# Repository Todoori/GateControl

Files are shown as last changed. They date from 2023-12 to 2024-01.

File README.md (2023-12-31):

# PCBProjectTemplate
Use this Repository as a Template to start your PCB Project. It contatins the general structure that should be used.
You can also add Images and [links](https://www.youtube.com/watch?v=dQw4w9WgXcQ) if needed. 

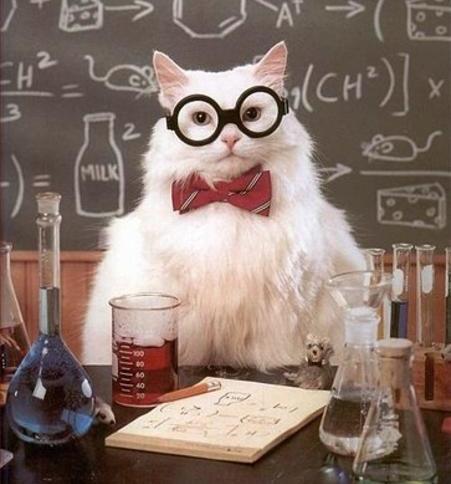
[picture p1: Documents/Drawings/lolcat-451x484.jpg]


## Assembly Instructions
- Do not solder those parts
- solder this solder bridge
- Do not soldet that solder bridge
- Use this part for R_example
- Be extra careful soldering this and that
- Do not aply to much heat to this part
- 
- 
- 

## Usage Instructions
- Try not to tuch this when PCB is on
- Use this software for programing that IC
- Here are some measurement Points
- 
- 
- 

## Additional Information

Feel free to add Information that you thing might be useful.

e.g. how a IC is connected on your Board:
### Pinout on Board

| PICO GPIO PIN  | Connected to |
| ---  | --- |
| 0  | |*|
| 1  | INT (CAN)|
| 2  | SPI0 SCK (CAN)|
| 3  | SPI0 TX (MOSI on Pico) (CAN)|
| 4  | SPI0 RX (MISO on Pico) (CAN)|
| 5  | SPIO0 CS (CAN)|
| 6  | LED Fault|
| 7  | |*|
| 8  | D7|
| 9  | D8|
| 10  | D9|
| 11  | D10|
| 12  | SPI1 RX (ADC)|
| 13  | SPI1 CS (ADC)|
| 14  | SPI1 SCK (ADC)|
| 15  | SPI1 TX (ADC)|
| 16  | D5|
| 17  | D6|
| 18  | D3|
| 19  | D4|
| 20  | D1|
| 21  | D2|
| 22  | |*|
| 23  | |*|
| 24  | |*|
| 25  | |*|
| 26  | A1|
| 27  | A2|
| 28  | SHUNT_ADC|

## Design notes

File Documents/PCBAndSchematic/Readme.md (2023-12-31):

# For easier it is a good Idea to export your schematic and pcb as PDF or Image, store them in here and display them in your main/readme. If you do not change their name but only update the file, you do not have to change the readme

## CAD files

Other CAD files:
DesignFiles/CAD/untitled.blend

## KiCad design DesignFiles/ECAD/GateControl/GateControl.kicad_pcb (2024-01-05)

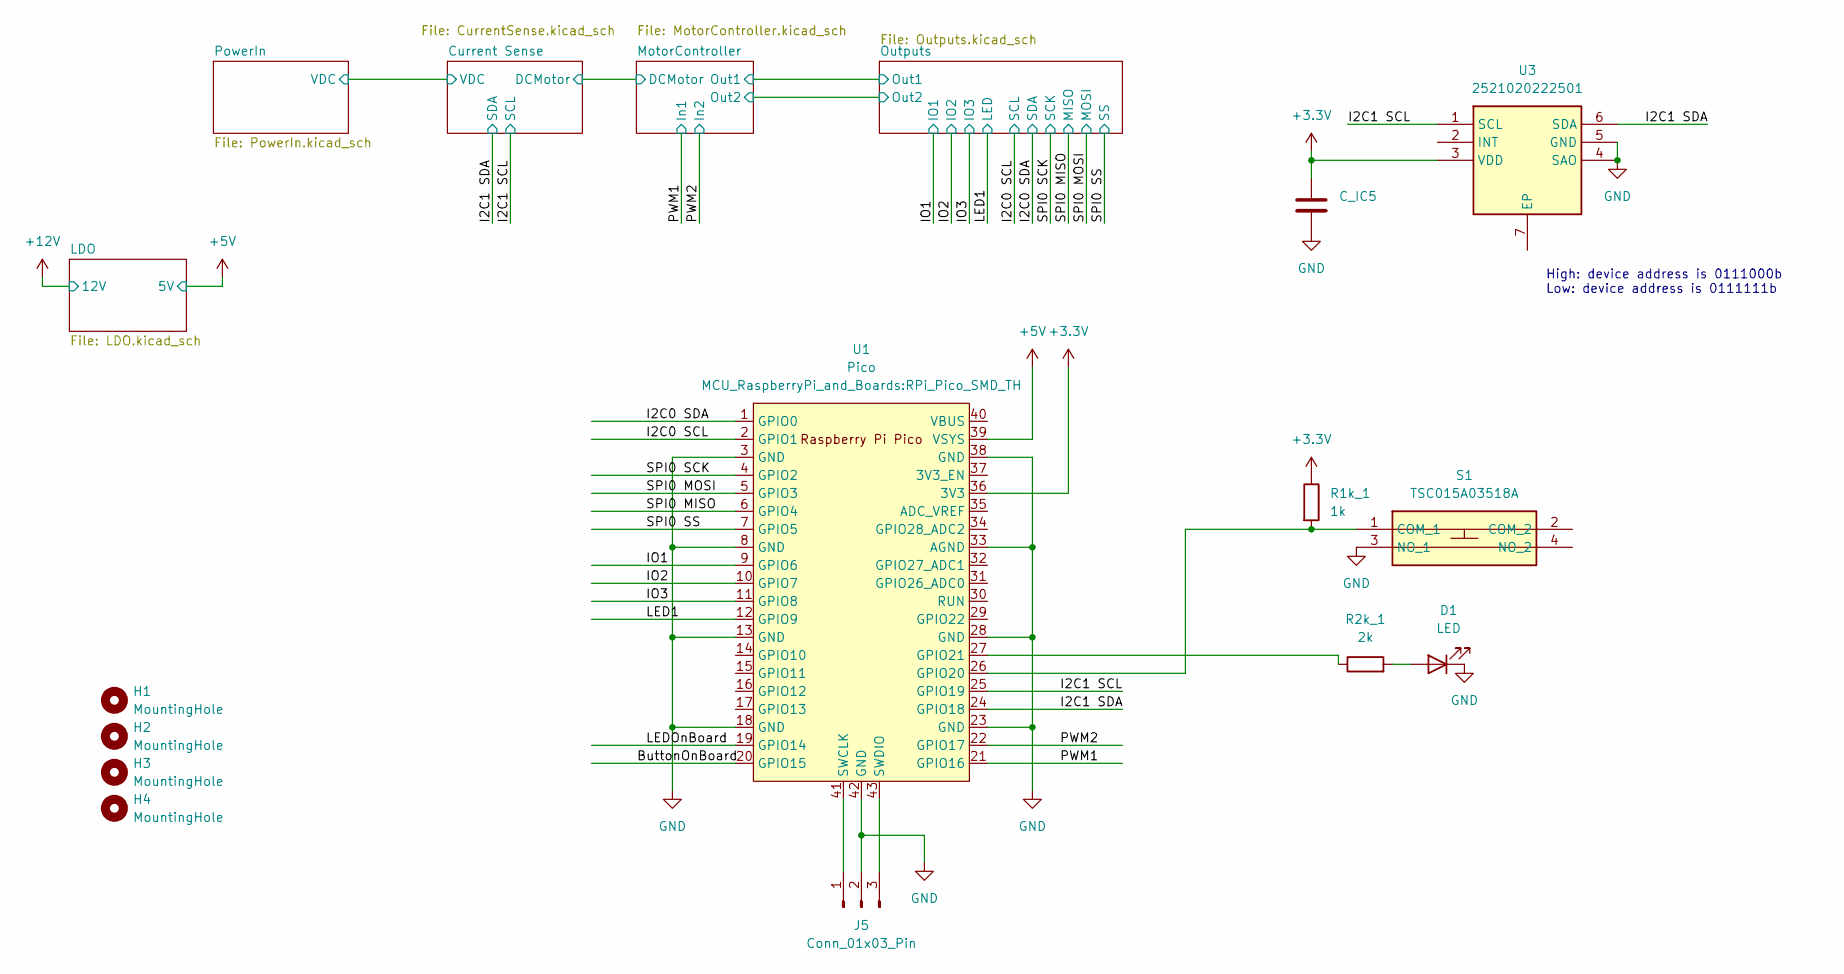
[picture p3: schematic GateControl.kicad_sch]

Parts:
C_IC5: C_Disc_D5.0mm_W2.5mm_P5.00mm
D1: LED; LED_0603_1608Metric_Pad1.05x0.95mm_HandSolder
H1, H2, H3, H4: MountingHole; MountingHole_3.2mm_M3_DIN965
J5: Conn_01x03_Pin; PinSocket_1x03_P2.54mm_Vertical
R1k_1: 1k; R_Axial_DIN0207_L6.3mm_D2.5mm_P7.62mm_Horizontal
R2k_1: 2k; R_0805_2012Metric_Pad1.20x1.40mm_HandSolder
S1: TSC015A03518A; Manufacturer_Part_Number TSC015A03518A
U1: Pico; RPi_Pico_SMD_TH
U3: 2521020222501; SON65P200X200X55-7N-D; Manufacturer_Part_Number 2521020222501; Mouser Part Number 710-2521020222501

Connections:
+3.3V: C_IC5.1, R1k_1.1, U1.36 (3V3), U3.3 (VDD); also elsewhere on the board
+5V: U1.39 (VSYS); also elsewhere on the board
/ButtonOnBoard: U1.20 (GPIO15)
/I2C0 SCL: U1.2 (GPIO1); also elsewhere on the board
/I2C0 SDA: U1.1 (GPIO0); also elsewhere on the board
/I2C1 SCL: U1.25 (GPIO19), U3.1 (SCL); also elsewhere on the board
/I2C1 SDA: U1.24 (GPIO18), U3.6 (SDA); also elsewhere on the board
/IO1: U1.9 (GPIO6); also elsewhere on the board
/IO2: U1.10 (GPIO7); also elsewhere on the board
/IO3: U1.11 (GPIO8); also elsewhere on the board
/LED1: U1.12 (GPIO9); also elsewhere on the board
/LEDOnBoard: U1.19 (GPIO14)
/PWM1: U1.21 (GPIO16); also elsewhere on the board
/PWM2: U1.22 (GPIO17); also elsewhere on the board
/SPI0 MISO: U1.6 (GPIO4); also elsewhere on the board
/SPI0 MOSI: U1.5 (GPIO3); also elsewhere on the board
/SPI0 SCK: U1.4 (GPIO2); also elsewhere on the board
/SPI0 SS: U1.7 (GPIO5); also elsewhere on the board
GND: C_IC5.2, D1.1 (K), J5.2, S1.3 (NO_1), U1.3 (GND), U1.8 (GND), U1.13 (GND), U1.18 (GND), U1.23 (GND), U1.28 (GND), U1.33 (AGND), U1.38 (GND), U1.42 (GND), U3.4 (SAO), U3.5 (GND); also elsewhere on the board
unnamed: D1.2 (A), R2k_1.2
unnamed: J5.1, U1.41 (SWCLK)
unnamed: J5.3, U1.43 (SWDIO)
unnamed: R1k_1.2, S1.1 (COM_1), U1.26 (GPIO20)
unnamed: R2k_1.1, U1.27 (GPIO21)

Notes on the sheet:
High: device address is 0111000b Low: device address is 0111111b

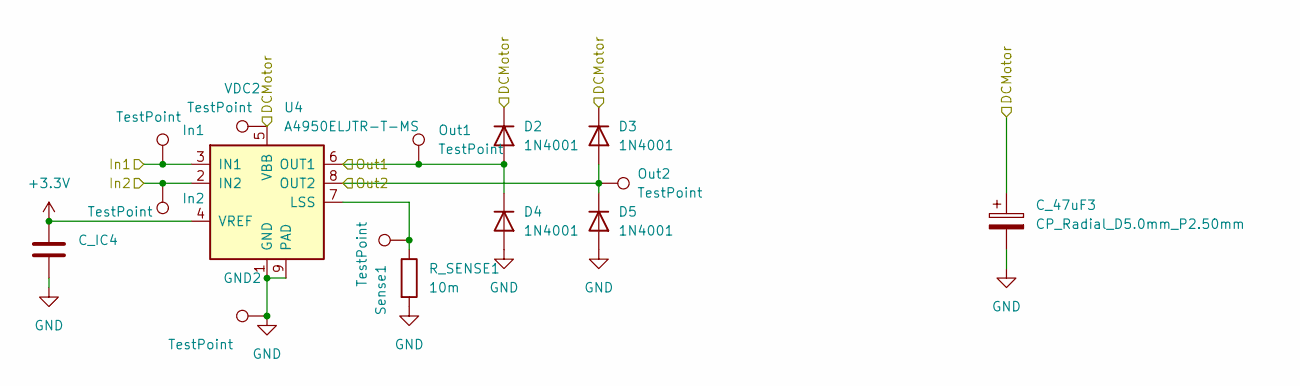
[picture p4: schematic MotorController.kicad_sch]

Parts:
C_47uF3: CP_Radial_D5.0mm_P2.50mm
C_IC4: C_Disc_D5.0mm_W2.5mm_P5.00mm
D2, D3, D4, D5: 1N4001; D_DO-41_SOD81_P10.16mm_Horizontal
GND2: TestPoint; TestPoint_THTPad_1.0x1.0mm_Drill0.5mm
In1, In2: TestPoint; TestPoint_THTPad_1.0x1.0mm_Drill0.5mm
Out1, Out2: TestPoint; TestPoint_THTPad_1.0x1.0mm_Drill0.5mm
R_SENSE1: 10m; R_1206_3216Metric_Pad1.30x1.75mm_HandSolder; Mfr. Part RTT06R010FTP
Sense1: TestPoint; TestPoint_THTPad_1.0x1.0mm_Drill0.5mm
U4: A4950ELJTR-T-MS; SOIC8
VDC2: TestPoint; TestPoint_THTPad_1.0x1.0mm_Drill0.5mm

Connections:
+3.3V: C_IC4.1, U4.4 (VREF); also elsewhere on the board
/Current Sense/DCMotor: C_47uF3.1, D2.1 (K), D3.1 (K), U4.5 (VBB), VDC2.1; also elsewhere on the board
/MotorController/Out1: D2.2 (A), D4.1 (K), Out1.1, U4.6 (OUT1); also elsewhere on the board
/MotorController/Out2: D3.2 (A), D5.1 (K), Out2.1, U4.8 (OUT2); also elsewhere on the board
/PWM1: In1.1, U4.3 (IN1); also elsewhere on the board
/PWM2: In2.1, U4.2 (IN2); also elsewhere on the board
GND: C_47uF3.2, C_IC4.2, D4.2 (A), D5.2 (A), GND2.1, R_SENSE1.2, U4.1 (GND), U4.9 (PAD); also elsewhere on the board
unnamed: R_SENSE1.1, Sense1.1, U4.7 (LSS)

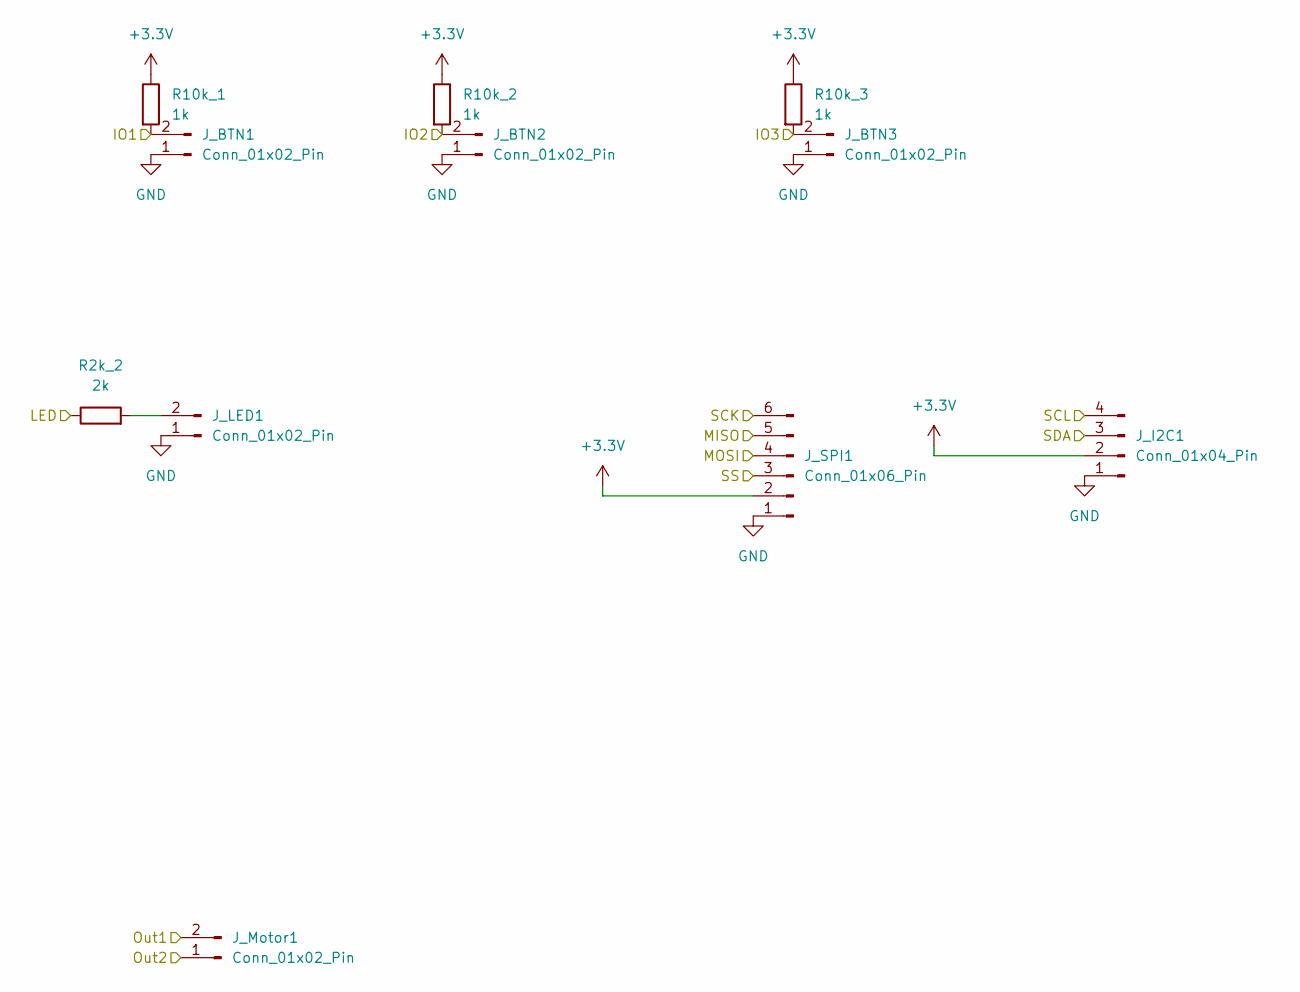
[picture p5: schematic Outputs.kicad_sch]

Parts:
J_BTN1, J_BTN2, J_BTN3: Conn_01x02_Pin; JST_XH_B2B-XH-A_1x02_P2.50mm_Vertical
J_I2C1: Conn_01x04_Pin; JST_XH_B4B-XH-A_1x04_P2.50mm_Vertical
J_LED1: Conn_01x02_Pin; JST_XH_B2B-XH-A_1x02_P2.50mm_Vertical
J_Motor1: Conn_01x02_Pin; JST_XH_B2B-XH-A_1x02_P2.50mm_Vertical
J_SPI1: Conn_01x06_Pin; JST_XH_B6B-XH-A_1x06_P2.50mm_Vertical
R2k_2: 2k; R_Axial_DIN0207_L6.3mm_D2.5mm_P7.62mm_Horizontal
R10k_1, R10k_2, R10k_3: 1k; R_Axial_DIN0207_L6.3mm_D2.5mm_P7.62mm_Horizontal

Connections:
+3.3V: J_I2C1.2, J_SPI1.2, R10k_1.1, R10k_2.1, R10k_3.1; also elsewhere on the board
/I2C0 SCL: J_I2C1.4; also elsewhere on the board
/I2C0 SDA: J_I2C1.3; also elsewhere on the board
/IO1: J_BTN1.2, R10k_1.2; also elsewhere on the board
/IO2: J_BTN2.2, R10k_2.2; also elsewhere on the board
/IO3: J_BTN3.2, R10k_3.2; also elsewhere on the board
/LED1: R2k_2.1; also elsewhere on the board
/MotorController/Out1: J_Motor1.2; also elsewhere on the board
/MotorController/Out2: J_Motor1.1; also elsewhere on the board
/SPI0 MISO: J_SPI1.5; also elsewhere on the board
/SPI0 MOSI: J_SPI1.4; also elsewhere on the board
/SPI0 SCK: J_SPI1.6; also elsewhere on the board
/SPI0 SS: J_SPI1.3; also elsewhere on the board
GND: J_BTN1.1, J_BTN2.1, J_BTN3.1, J_I2C1.1, J_LED1.1, J_SPI1.1; also elsewhere on the board
unnamed: J_LED1.2, R2k_2.2

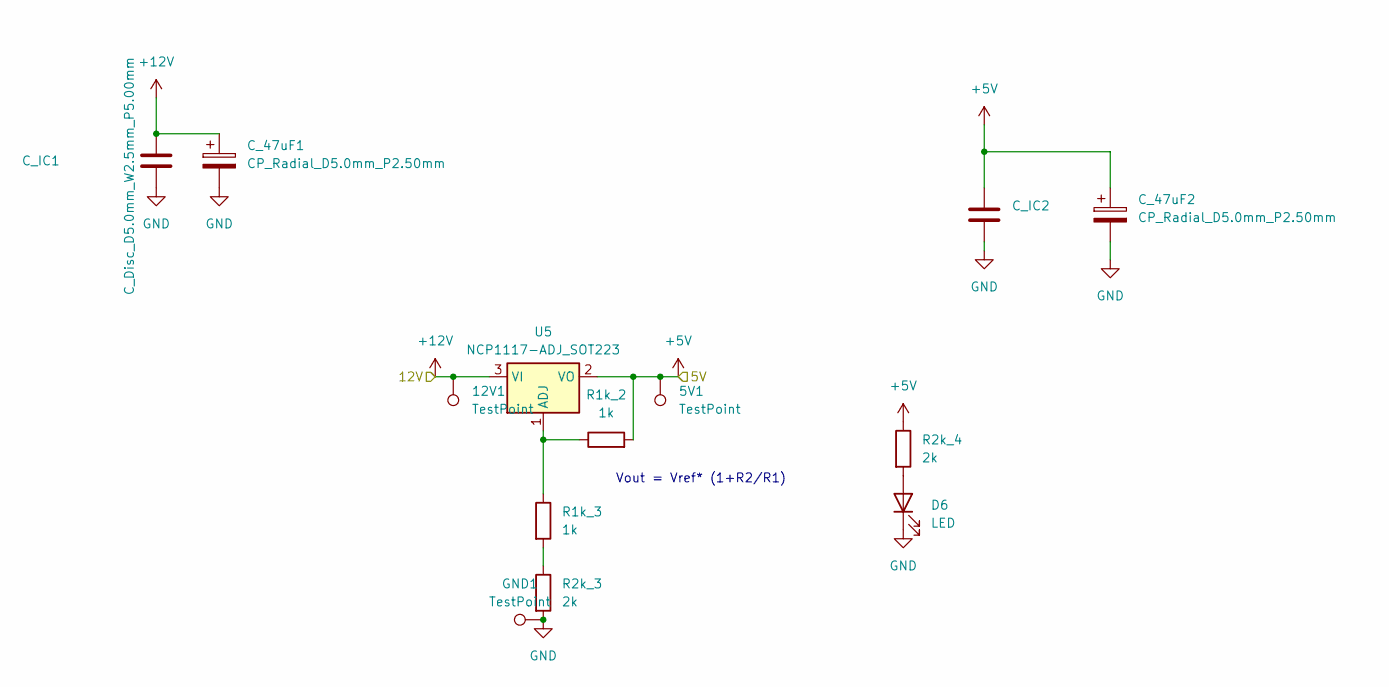
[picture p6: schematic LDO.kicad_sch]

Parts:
5V1, 12V1: TestPoint; TestPoint_THTPad_1.0x1.0mm_Drill0.5mm
C_47uF1, C_47uF2: CP_Radial_D5.0mm_P2.50mm
C_IC1, C_IC2: C_Disc_D5.0mm_W2.5mm_P5.00mm
D6: LED; LED_0603_1608Metric_Pad1.05x0.95mm_HandSolder
GND1: TestPoint; TestPoint_THTPad_1.0x1.0mm_Drill0.5mm
R1k_2, R1k_3: 1k; R_Axial_DIN0207_L6.3mm_D2.5mm_P7.62mm_Horizontal
R2k_3: 2k; R_Axial_DIN0207_L6.3mm_D2.5mm_P7.62mm_Horizontal
R2k_4: 2k; R_0805_2012Metric_Pad1.20x1.40mm_HandSolder
U5: NCP1117-ADJ_SOT223; SOT-223-3_TabPin2

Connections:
+5V: 5V1.1, C_47uF2.1, C_IC2.1, R1k_2.2, R2k_4.1, U5.2 (VO); also elsewhere on the board
+12V: 12V1.1, C_47uF1.1, C_IC1.1, U5.3 (VI); also elsewhere on the board
GND: C_47uF1.2, C_47uF2.2, C_IC1.2, C_IC2.2, D6.1 (K), GND1.1, R2k_3.2; also elsewhere on the board
unnamed: D6.2 (A), R2k_4.2
unnamed: R1k_3.2, R2k_3.1
unnamed: R1k_2.1, R1k_3.1, U5.1 (ADJ)

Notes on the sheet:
Vout = Vref* (1+R2/R1)

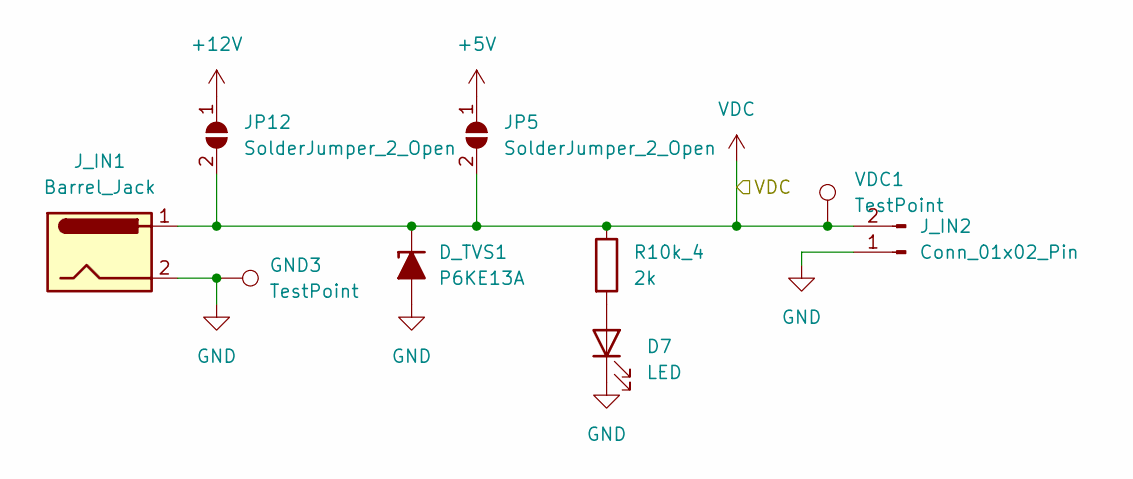
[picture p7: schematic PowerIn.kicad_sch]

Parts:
D7: LED; LED_0603_1608Metric_Pad1.05x0.95mm_HandSolder
D_TVS1: P6KE13A; D_DO-15_P5.08mm_Vertical_KathodeUp
GND3: TestPoint; TestPoint_THTPad_1.0x1.0mm_Drill0.5mm
JP5, JP12: SolderJumper_2_Open; SolderJumper-2_P1.3mm_Open_RoundedPad1.0x1.5mm
J_IN1: Barrel_Jack; BarrelJack_2,inner_5,5outer_DC-005 2.0
J_IN2: Conn_01x02_Pin; JST_XH_B2B-XH-A_1x02_P2.50mm_Vertical
R10k_4: 2k; R_0805_2012Metric_Pad1.20x1.40mm_HandSolder
VDC1: TestPoint; TestPoint_THTPad_1.0x1.0mm_Drill0.5mm

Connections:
+5V: JP5.1 (A); also elsewhere on the board
+12V: JP12.1 (A); also elsewhere on the board
GND: D7.1 (K), D_TVS1.2 (A), GND3.1, J_IN1.2, J_IN2.1; also elsewhere on the board
unnamed: D7.2 (A), R10k_4.2
VDC: D_TVS1.1 (K), JP5.2 (B), JP12.2 (B), J_IN1.1, J_IN2.2, R10k_4.1, VDC1.1; also elsewhere on the board

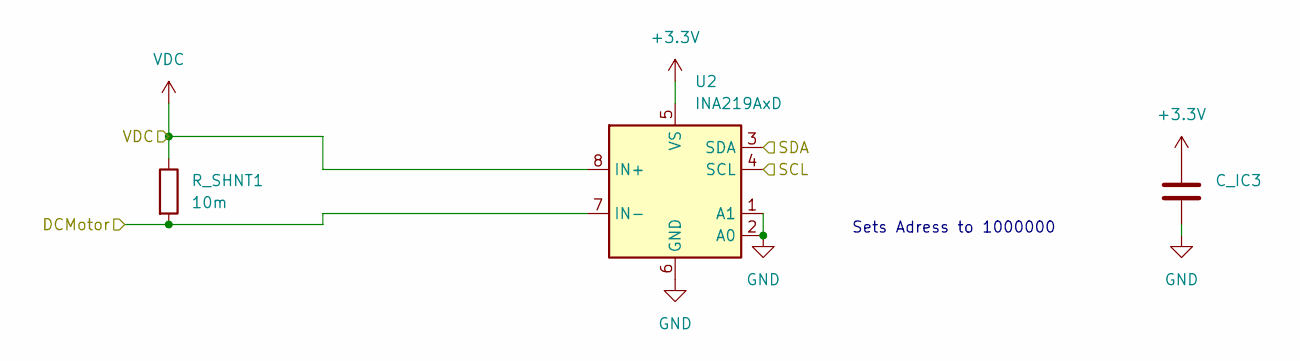
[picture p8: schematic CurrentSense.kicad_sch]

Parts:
C_IC3: C_Disc_D5.0mm_W2.5mm_P5.00mm
R_SHNT1: 10m; R_1206_3216Metric_Pad1.30x1.75mm_HandSolder; Mfr. Part RTT06R010FTP
U2: INA219AxD; SOIC-8_3.9x4.9mm_P1.27mm

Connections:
+3.3V: C_IC3.1, U2.5 (VS); also elsewhere on the board
/Current Sense/DCMotor: R_SHNT1.2, U2.7 (IN-); also elsewhere on the board
/I2C1 SCL: U2.4 (SCL); also elsewhere on the board
/I2C1 SDA: U2.3 (SDA); also elsewhere on the board
GND: C_IC3.2, U2.1 (A1), U2.2 (A0), U2.6 (GND); also elsewhere on the board
VDC: R_SHNT1.1, U2.8 (IN+); also elsewhere on the board

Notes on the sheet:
Sets Adress to 1000000

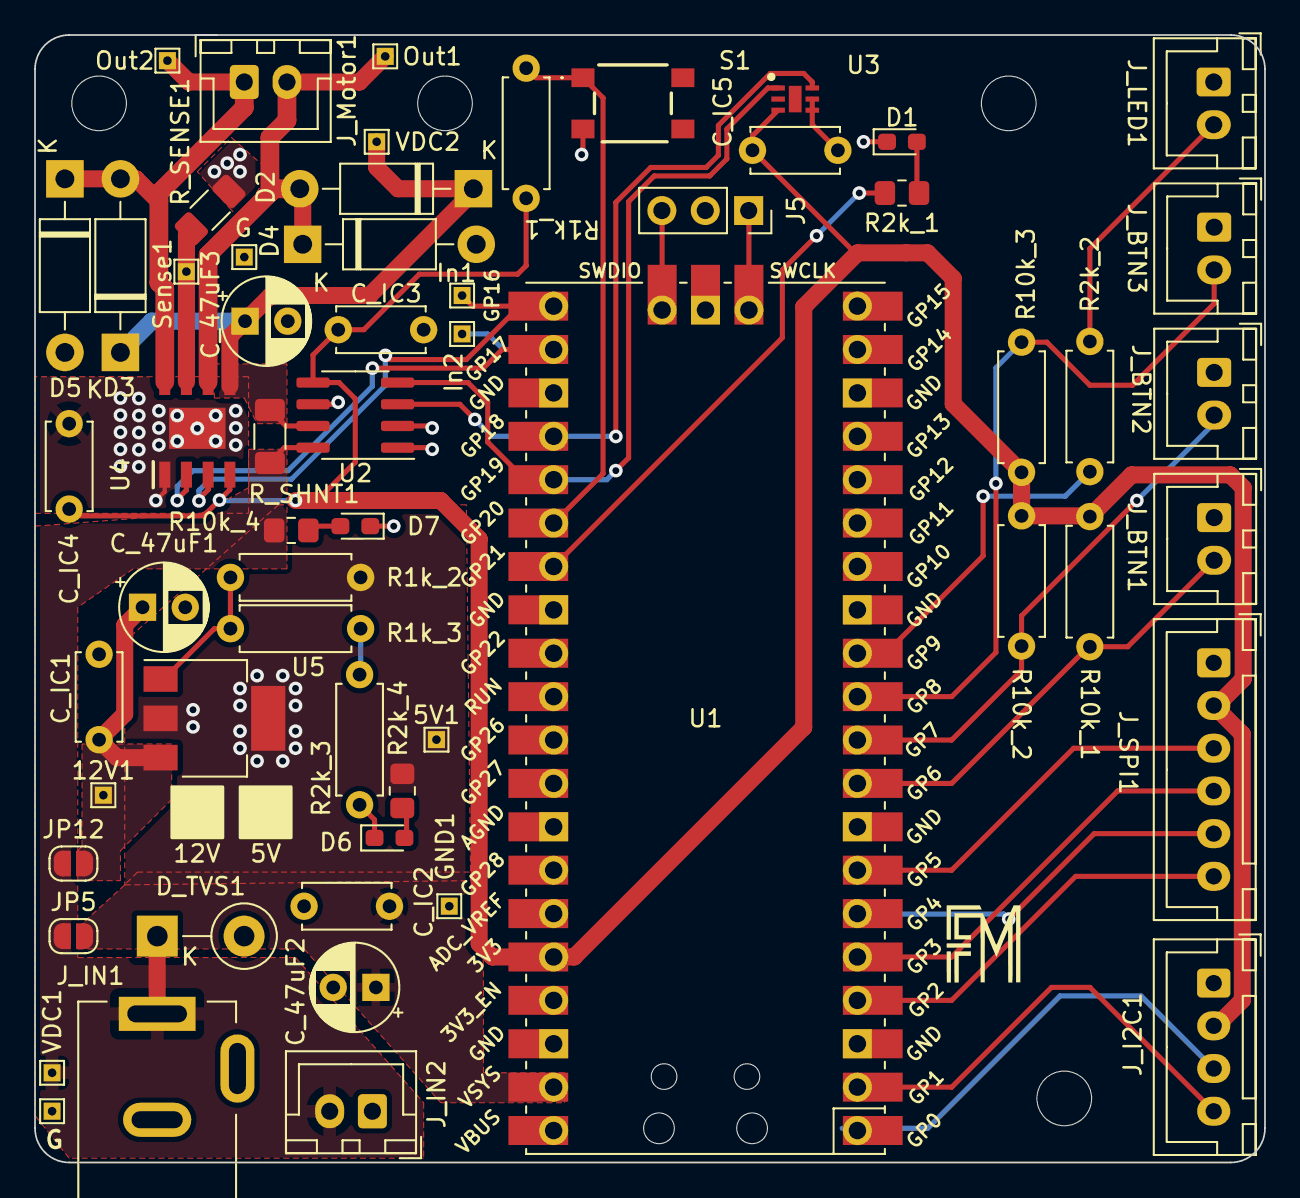
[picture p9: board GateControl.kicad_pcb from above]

Board: 2 copper layers, 72.0 x 66.0 mm, 63 parts (0 on the bottom side), 33 nets.

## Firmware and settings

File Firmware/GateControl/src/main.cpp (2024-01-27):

#include <Arduino.h>
#include <Wire.h>
#include <Adafruit_INA219.h>

Adafruit_INA219 ina219;

#define PWM1 16
#define PWM2 17
#define LED1 25
#define LED2 21
#define BTN 20
#define BTN1 6
#define BTN2 7
#define BTN3 8


float RShunt = 0.01 ; //10mR
float shuntvoltage_mV = 0;
float busvoltage = 0;
float current_mA = 0;
int speed = 100; //PWM Value out of 250


void setup(void) 
{
  analogWriteFreq(2000); //2khz

  Serial.begin(115200);
  Serial.println("Hello!");
  
  // Initialize the INA219.
  Serial.println("initialising INA219...");
  Wire1.setSDA(18);
  Wire1.setSCL(19);
  if (! ina219.begin(&Wire1)) {
    Serial.println("Failed to find INA219 chip");
    while (1) { delay(10); }
  }

  // Initialize Pin Modes  
  Serial.println("initialising Pin Modes...");
  pinMode(PWM1, OUTPUT);
  pinMode(PWM2, OUTPUT);
  pinMode(LED1, OUTPUT);
  pinMode(LED2, OUTPUT);
  pinMode(BTN, INPUT);
  pinMode(BTN1, INPUT);
  pinMode(BTN2, INPUT);
  pinMode(BTN3, INPUT);

  digitalWrite(LED1, HIGH);
  digitalWrite(LED2, HIGH);
  delay(500);
  digitalWrite(LED1, LOW);
  digitalWrite(LED2, LOW);
  Serial.println("Setup finished");
}

void measureShunt()
{
  shuntvoltage_mV = ina219.getShuntVoltage_mV();
  if (shuntvoltage_mV < 0)
    shuntvoltage_mV = 0;
  busvoltage = ina219.getBusVoltage_V();
  current_mA = shuntvoltage_mV/RShunt;
  
  Serial.print("Bus Voltage:   "); Serial.print(busvoltage); Serial.println(" V");
  Serial.print("Shunt Voltage: "); Serial.print(shuntvoltage_mV, 3); Serial.println(" mV");
  Serial.print("Current:       "); Serial.print(current_mA, 3); Serial.println(" mA");
  Serial.println("");
}

void Motorcontrol(int mode)
{

  if (mode == 0) //off (stdby)
  { 
    digitalWrite(PWM2, LOW);
    digitalWrite(LED2, LOW);
    digitalWrite(PWM1, LOW);
    digitalWrite(LED1, LOW);
    delay(500);
  }
    if (mode == 1) //Forward
  { 
    //break
    analogWrite(PWM1, 255);
    analogWrite(PWM2, 255);
    delay(200);
    analogWrite(PWM2, 0);
    digitalWrite(LED2, LOW);
    analogWrite(PWM1, speed);
    digitalWrite(LED1, HIGH);
    delay(500);
  }
    if (mode == 2) //Reveerse
  { 
    //break
    analogWrite(PWM1, 255);
    analogWrite(PWM2, 255);
    delay(200);
    analogWrite(PWM1, 0);
    digitalWrite(LED1, LOW);
    analogWrite(PWM2, speed);
    digitalWrite(LED2, HIGH);
    delay(500);
  }
    if (mode == 3) //Break
    {
    analogWrite(PWM1, 255);
    digitalWrite(LED1, HIGH);
    analogWrite(PWM2, 255);
    digitalWrite(LED2, HIGH);
    delay(500);
    }
}



void loop(void) 
{

  measureShunt();

  //Button readings
  if (!digitalRead(BTN))
  {
    Motorcontrol(0);
      if (!digitalRead(BTN1) && speed <235)
      {
        speed = speed + 20;
        Serial.print("Speed: ");
        Serial.println(speed);
        delay(20);
      }
      if (!digitalRead(BTN2) && speed >20)
      {
        speed = speed -20;
        Serial.print("Speed: ");
        Serial.println(speed);
        delay(20);
      }
  }
  if (!digitalRead(BTN1))
  {
    Motorcontrol(1);
  }
    if (!digitalRead(BTN2))
  {
    Motorcontrol(2);
  }
    if (!digitalRead(BTN3))
  {
    Motorcontrol(3);
  }


  delay(100);
}

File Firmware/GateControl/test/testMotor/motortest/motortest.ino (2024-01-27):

#define PWM1 16
#define PWM2 17
#define LED1 25
#define LED2 21
#define BTN 20

int mode = 0; //0 = off, 1 =PWM1, 2 = PWM3

void setup() {

  analogWriteFreq(2000); //2khz

  Serial.begin(115200);
  Serial.println("initialising Pin Modes...");
  pinMode(PWM1, OUTPUT);
  pinMode(PWM2, OUTPUT);
  pinMode(LED1, OUTPUT);
  pinMode(LED2, OUTPUT);
  pinMode(BTN, INPUT);

  digitalWrite(LED1, HIGH);
  digitalWrite(LED2, HIGH);
  delay(500);
  digitalWrite(LED1, LOW);
  digitalWrite(LED2, LOW);

}

void Motorcontrol()
{
  if (mode == 0)
  { 
    digitalWrite(PWM2, LOW);
    digitalWrite(LED2, LOW);
    digitalWrite(PWM1, LOW);
    digitalWrite(LED1, LOW);
    delay(500);
  }
    if (mode == 1)
  { 
    analogWrite(PWM2, 0);
    digitalWrite(LED2, LOW);
    delay(500);
    analogWrite(PWM1, 5);
    digitalWrite(LED1, HIGH);
    delay(500);
  }
    if (mode == 2)
  { 
    analogWrite(PWM1, 0);
    digitalWrite(LED1, LOW);
    delay(500);
    analogWrite(PWM2, 20);
    digitalWrite(LED2, HIGH);
    delay(500);
  }
}

void Buttonpressed()
{
  mode ++;
  if (mode == 3)
  {
    mode = 0;
  }
  Serial.print("Mode: ");
  Serial.println(mode);
}

void loop() {
  // put your main code here, to run repeatedly:
if (!digitalRead(BTN))
{
  Buttonpressed();
  Motorcontrol();
}
delay(10);
}

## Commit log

2024-01-01 finished shematic, started PCB Layout
    [CurrentSense.kicad_sch, GateControl.kicad_pcb, GateControl.kicad_sch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]
2024-01-02 finished PCB
    [CurrentSense.kicad_sch, GateControl.kicad_pcb, GateControl.kicad_sch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]
